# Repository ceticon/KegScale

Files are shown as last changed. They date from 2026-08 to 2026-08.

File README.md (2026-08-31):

# 🍺 KegScale

**KegScale** är en Raspberry Pi-baserad våg för att mäta hur mycket öl som finns kvar i ett Corneliusfat.

Systemet använder fyra lastceller tillsammans med en HX711 och en Raspberry Pi 5. Vikten läses kontinuerligt och presenteras i ett webbaserat gränssnitt byggt med Flask.

KegScale har två webbsidor:

- **KegScale Main** – ren visningssida för vikt, mängd öl och fyllnadsgrad.
- **KegScale Setup** – används för inställningar och hantering av vågen.

På så sätt kan huvudsidan visas för andra utan risk att någon av misstag ändrar inställningar eller nollställer vågen.

---

## 🖥️ KegScale Main

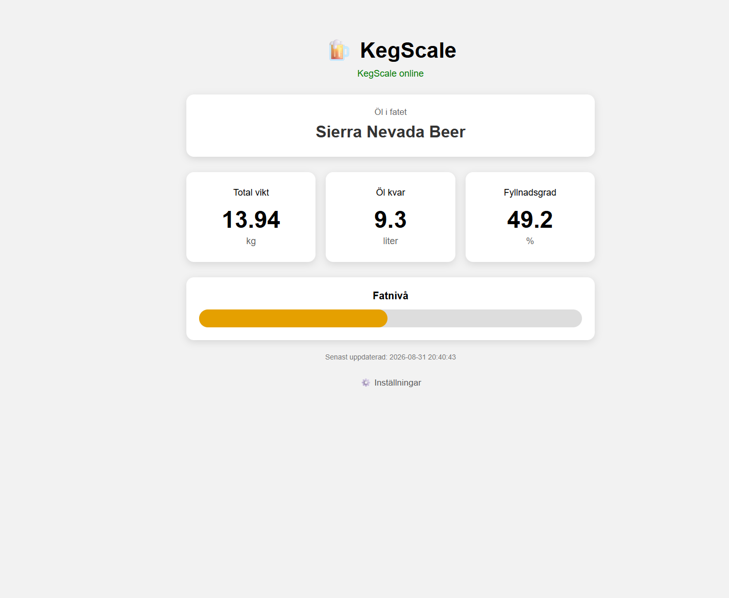
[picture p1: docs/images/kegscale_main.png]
KegScale Main


Huvudsidan finns på:

```text
http://<raspberry-pi-ip>:5000/
```

Den visar:

- Ölets namn
- Total vikt
- Mängd öl kvar i liter
- Fyllnadsgrad i procent
- Grafisk nivåindikator
- Online/offline-status
- Tidpunkt för senaste mätningen

Huvudsidan är avsedd som en **ren informationssida** och innehåller inga funktioner som ändrar KegScale.

Längst ner finns en diskret länk till inställningssidan.

---

## ⚙️ KegScale Setup

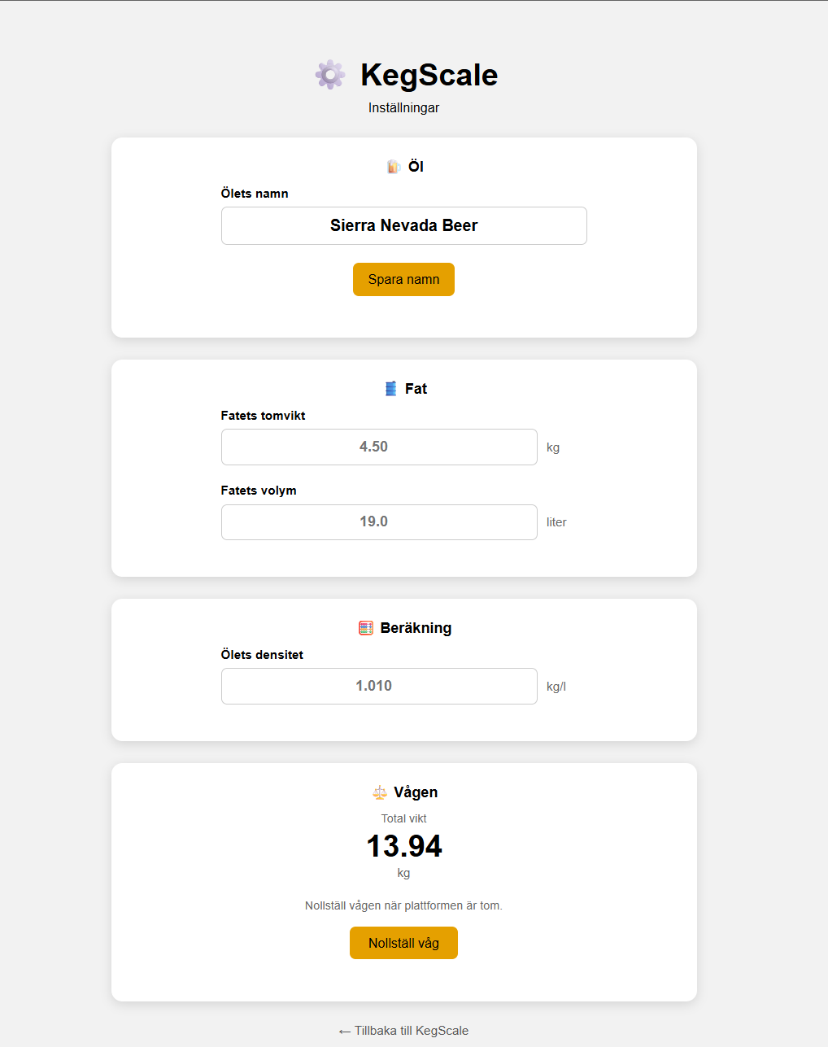
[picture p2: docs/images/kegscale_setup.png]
KegScale Setup


Inställningssidan finns på:

```text
http://<raspberry-pi-ip>:5000/setup
```

Setup-sidan används för konfiguration och handhavande.

Den innehåller:

- Ölets namn
- Fatets tomvikt
- Fatets volym
- Ölets densitet
- Aktuell total vikt
- Nollställning av vågen

Den aktuella vikten visas direkt på setup-sidan för att göra tareringen tydligare.

> **Observera:** Ölnamn och nollställning av vågen är implementerade.  
> Fatets tomvikt, volym och ölets densitet visas på Setup-sidan men ska kopplas till konfigurationen i ett kommande steg.

---

## 🔧 Hardware

KegScale använder:

- Raspberry Pi 5
- HX711 load cell amplifier
- 4 × 50 kg lastceller
- Kopplingskort för lastcellerna
- 19 liters Corneliusfat

Fyra 50 kg lastceller ger en nominell total kapacitet på cirka **200 kg**.

### HX711

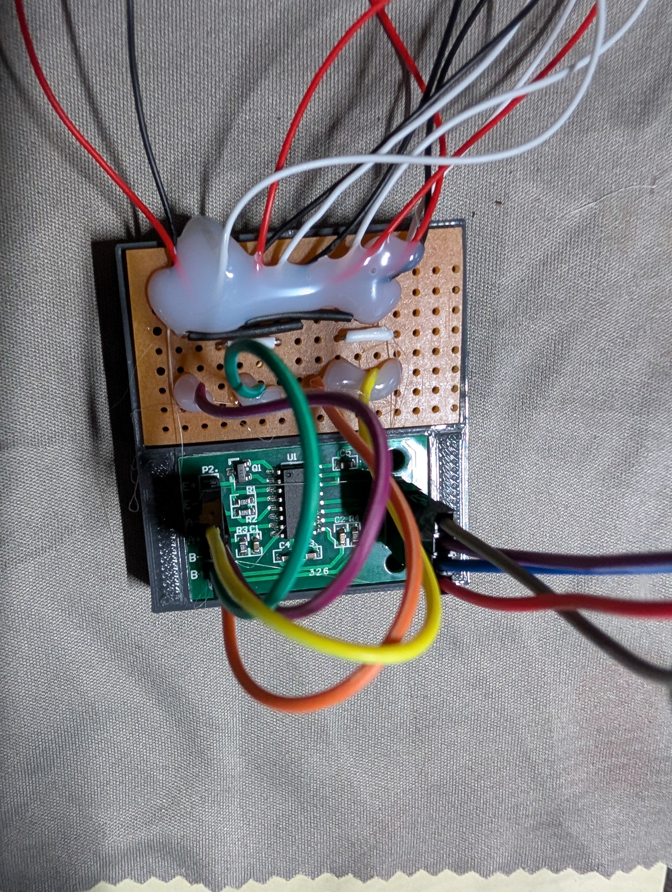
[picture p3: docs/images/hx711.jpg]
HX711


HX711 förstärker den mycket svaga signalen från lastcellerna och omvandlar den till ett digitalt 24-bitars mätvärde som Raspberry Pi kan läsa.

### Anslutning till Raspberry Pi

| HX711 | Raspberry Pi |
|---|---|
| DT / DATA | GPIO 6 |
| SCK / CLOCK | GPIO 5 |
| GND | GND |
| VCC | Matning |

Programmet använder BCM-numrering:

```python
DATA_PIN = 6
CLOCK_PIN = 5
```

---

## 🔌 Kopplingsschema

Fritzing-projekt och kopplingsschema finns i:

```text
hardware/
├── KegScale_bb.pdf
└── KegScale.fzz
```

`KegScale.fzz` kan öppnas och redigeras i Fritzing.

`KegScale_bb.pdf` innehåller kopplingsschemat i PDF-format.

---

## ⚖️ Så fungerar KegScale

Kommunikationen mellan hårdvara och webbgränssnitt ser ut så här:

```text
4 × Load cells
       │
       ▼
     HX711
       │
       ▼
Raspberry Pi GPIO
       │
       ▼
  kegscale.py
       │
       ▼
 kegscale.json
       │
       ▼
     Flask
       │
       ▼
   JavaScript
       │
       ▼
  Web browser
```

`kegscale.py` är den enda processen som kommunicerar direkt med GPIO och HX711.

Flask behöver därför inte komma åt GPIO utan läser den information som `kegscale.py` skriver till JSON.

Det gör att vågfunktionen och webbservern hålls separerade.

---

## 📏 Mätning och filtrering

För varje viktmätning:

1. 30 mätvärden läses från HX711.
2. Mätvärdena sorteras.
3. De 5 lägsta värdena tas bort.
4. De 5 högsta värdena tas bort.
5. Medelvärdet av resterande 20 mätningar beräknas.

Detta ger en stabilare vikt och minskar påverkan från enstaka störningar.

Små variationer runt noll filtreras också bort:

```python
if abs(vikt_gram) < 5:
    vikt_gram = 0.0
```

---

## 🎯 Kalibrering

Nuvarande kalibreringsfaktor:

```python
KALIBRERINGS_FAKTOR = 21.04
```

Vågen har kalibrerats med en känd vikt på cirka **3910 gram**.

Eftersom belastning gör HX711-råvärdet mer negativt beräknas vikten med:

```python
vikt_gram = -differens / KALIBRERINGS_FAKTOR
```

En separat fil finns för felsökning och kalibrering:

```text
debug_vikt.py
```

---

## 🍺 Konfiguration

Grundinställningarna finns i:

```text
config.json
```

Exempel:

```json
{
    "beer_name": "Munich Helles",
    "keg_tare_kg": 4.5,
    "keg_capacity_l": 19.0,
    "beer_density_kg_per_l": 1.01
}
```

### `beer_name`

Namnet på ölet som finns i fatet.

Ölnamnet kan ändras från **KegScale Setup** och visas sedan på **KegScale Main**.

### `keg_tare_kg`

Vikten på det tomma fatet.

Den verkliga tomvikten bör mätas för det Corneliusfat som används.

### `keg_capacity_l`

Fatets nominella volym i liter.

### `beer_density_kg_per_l`

Ölets ungefärliga densitet i kg/liter.

---

## 🧮 Beräkning av mängden öl

Först beräknas ölets vikt:

```text
Ölets vikt = Total vikt - Fatets tomvikt
```

Därefter beräknas volymen:

```text
Liter öl = Ölets vikt / Ölets densitet
```

Fyllnadsgraden beräknas med:

```text
Fyllnadsgrad = Liter öl / Fatets kapacitet × 100
```

Resultatet begränsas till:

```text
0 – 100 %
```

---

## 📄 Statusdata

`kegscale.py` skriver kontinuerligt aktuell information till:

```text
kegscale.json
```

Exempel:

```json
{
    "beer_name": "Munich Helles",
    "weight_g": 13945.1,
    "weight_kg": 13.945,
    "beer_weight_kg": 9.445,
    "beer_liters": 9.35,
    "fill_percent": 49.2,
    "keg_tare_kg": 4.5,
    "keg_capacity_l": 19.0,
    "beer_density_kg_per_l": 1.01,
    "timestamp": "2026-08-31 19:30:00"
}
```

`kegscale.json` är en runtime-fil och behöver normalt inte versionshanteras i Git.

---

## 🔄 Nollställning från Setup

Vågen kan nollställas från **KegScale Setup**.

Webbläsaren skickar:

```text
POST /api/tare
```

Flask skriver kommandot till:

```text
control.json
```

Exempel:

```json
{
    "tare": true
}
```

`kegscale.py` upptäcker kommandot, utför tareringen och återställer därefter kommandot.

```text
KegScale Setup
      │
      ▼
 POST /api/tare
      │
      ▼
    Flask
      │
      ▼
 control.json
      │
      ▼
 kegscale.py
      │
      ▼
    HX711
```

Flask kommunicerar alltså aldrig direkt med GPIO.

---

## ✏️ Ändra ölnamn

Ölnamnet ändras från **KegScale Setup**.

Flask använder:

```text
GET  /api/beer-name
POST /api/beer-name
```

När exempelvis:

```text
Munich Helles
```

ändras till:

```text
Czech Pilsner
```

sparas det nya namnet i `config.json`.

`kegscale.py` läser konfigurationen och det nya namnet visas därefter på KegScale Main.

---

## 📁 Projektstruktur

```text
KegScale/
├── .gitignore
├── config.json
├── debug_vikt.py
├── docs/
│   └── images/
│       ├── hx711.jpg
│       ├── kegscale_main.png
│       └── kegscale_setup.png
├── hardware/
│   ├── KegScale_bb.pdf
│   └── KegScale.fzz
├── kegscale.py
├── README.md
├── requirements.txt
├── test_vikt_pi5.py
└── web/
    ├── app.py
    ├── static/
    │   ├── script.js
    │   └── style.css
    └── templates/
        ├── index.html
        └── setup.html
```

Runtime-filerna:

```text
kegscale.json
control.json
```

exkluderas från Git via `.gitignore`.

---

## 🐍 Python environment

Skapa en virtuell Python-miljö:

```bash
python3 -m venv myenv
```

Aktivera den:

```bash
source myenv/bin/activate
```

Installera beroenden:

```bash
pip install -r requirements.txt
```

---

## 🚀 Starta KegScale

KegScale består av två separata processer:

1. Vågen
2. Flask-webbservern

### Terminal 1 – KegScale

```bash
cd ~/Projects/KegScale
source myenv/bin/activate
python kegscale.py
```

### Terminal 2 – Flask

```bash
cd ~/Projects/KegScale
source myenv/bin/activate
cd web
python app.py
```

Flask-servern körs på:

```text
0.0.0.0:5000
```

### KegScale Main

```text
http://<raspberry-pi-ip>:5000/
```

### KegScale Setup

```text
http://<raspberry-pi-ip>:5000/setup
```

---

## 🌐 API

### Läs vågdata

```text
GET /api/weight
```

Returnerar bland annat:

- Ölnamn
- Total vikt
- Mängd öl
- Fyllnadsgrad
- Tidstämpel
- Online/offline-status

### Nollställ vågen

```text
POST /api/tare
```

### Läs ölnamn

```text
GET /api/beer-name
```

### Ändra ölnamn

```text
POST /api/beer-name
```

Exempel:

```json
{
    "beer_name": "Munich Helles"
}
```

---

## ✅ Current features

- [x] Raspberry Pi 5
- [x] HX711 communication
- [x] 4 × 50 kg load cells
- [x] Digital filtering
- [x] Scale calibration
- [x] Weight in grams and kilograms
- [x] Beer volume calculation
- [x] Keg fill percentage
- [x] JSON status
- [x] Flask web interface
- [x] Automatic web updates
- [x] Online/offline detection
- [x] Graphical keg level
- [x] Separate Main and Setup pages
- [x] Read-only Main page
- [x] Editable beer name from Setup
- [x] Web-based scale tare
- [x] Live total weight on Setup page
- [x] Hardware documentation
- [x] Fritzing project and PDF wiring diagram

---

## 🔮 Planned features

- [ ] Save keg tare weight from Setup
- [ ] Use current scale weight as keg tare weight
- [ ] Save keg capacity from Setup
- [ ] Save beer density from Setup
- [ ] Support different keg sizes
- [ ] Save scale offset between restarts
- [ ] Automatic startup with systemd
- [ ] Historical consumption data
- [ ] Multiple keg support

---

## 📌 Status

KegScale är nu ett fungerande Raspberry Pi-baserat mätsystem med separat vågprocess och Flask-webbserver.

Vågen är kalibrerad och testad. **KegScale Main** visar aktuell vikt, mängden öl och fatets fyllnadsgrad, medan **KegScale Setup** används för inställningar och tarering.

Nästa utvecklingssteg är att göra fatets tomvikt, volym och ölets densitet fullt redigerbara från Setup-sidan.

🍺 **Current keg: Munich Helles**

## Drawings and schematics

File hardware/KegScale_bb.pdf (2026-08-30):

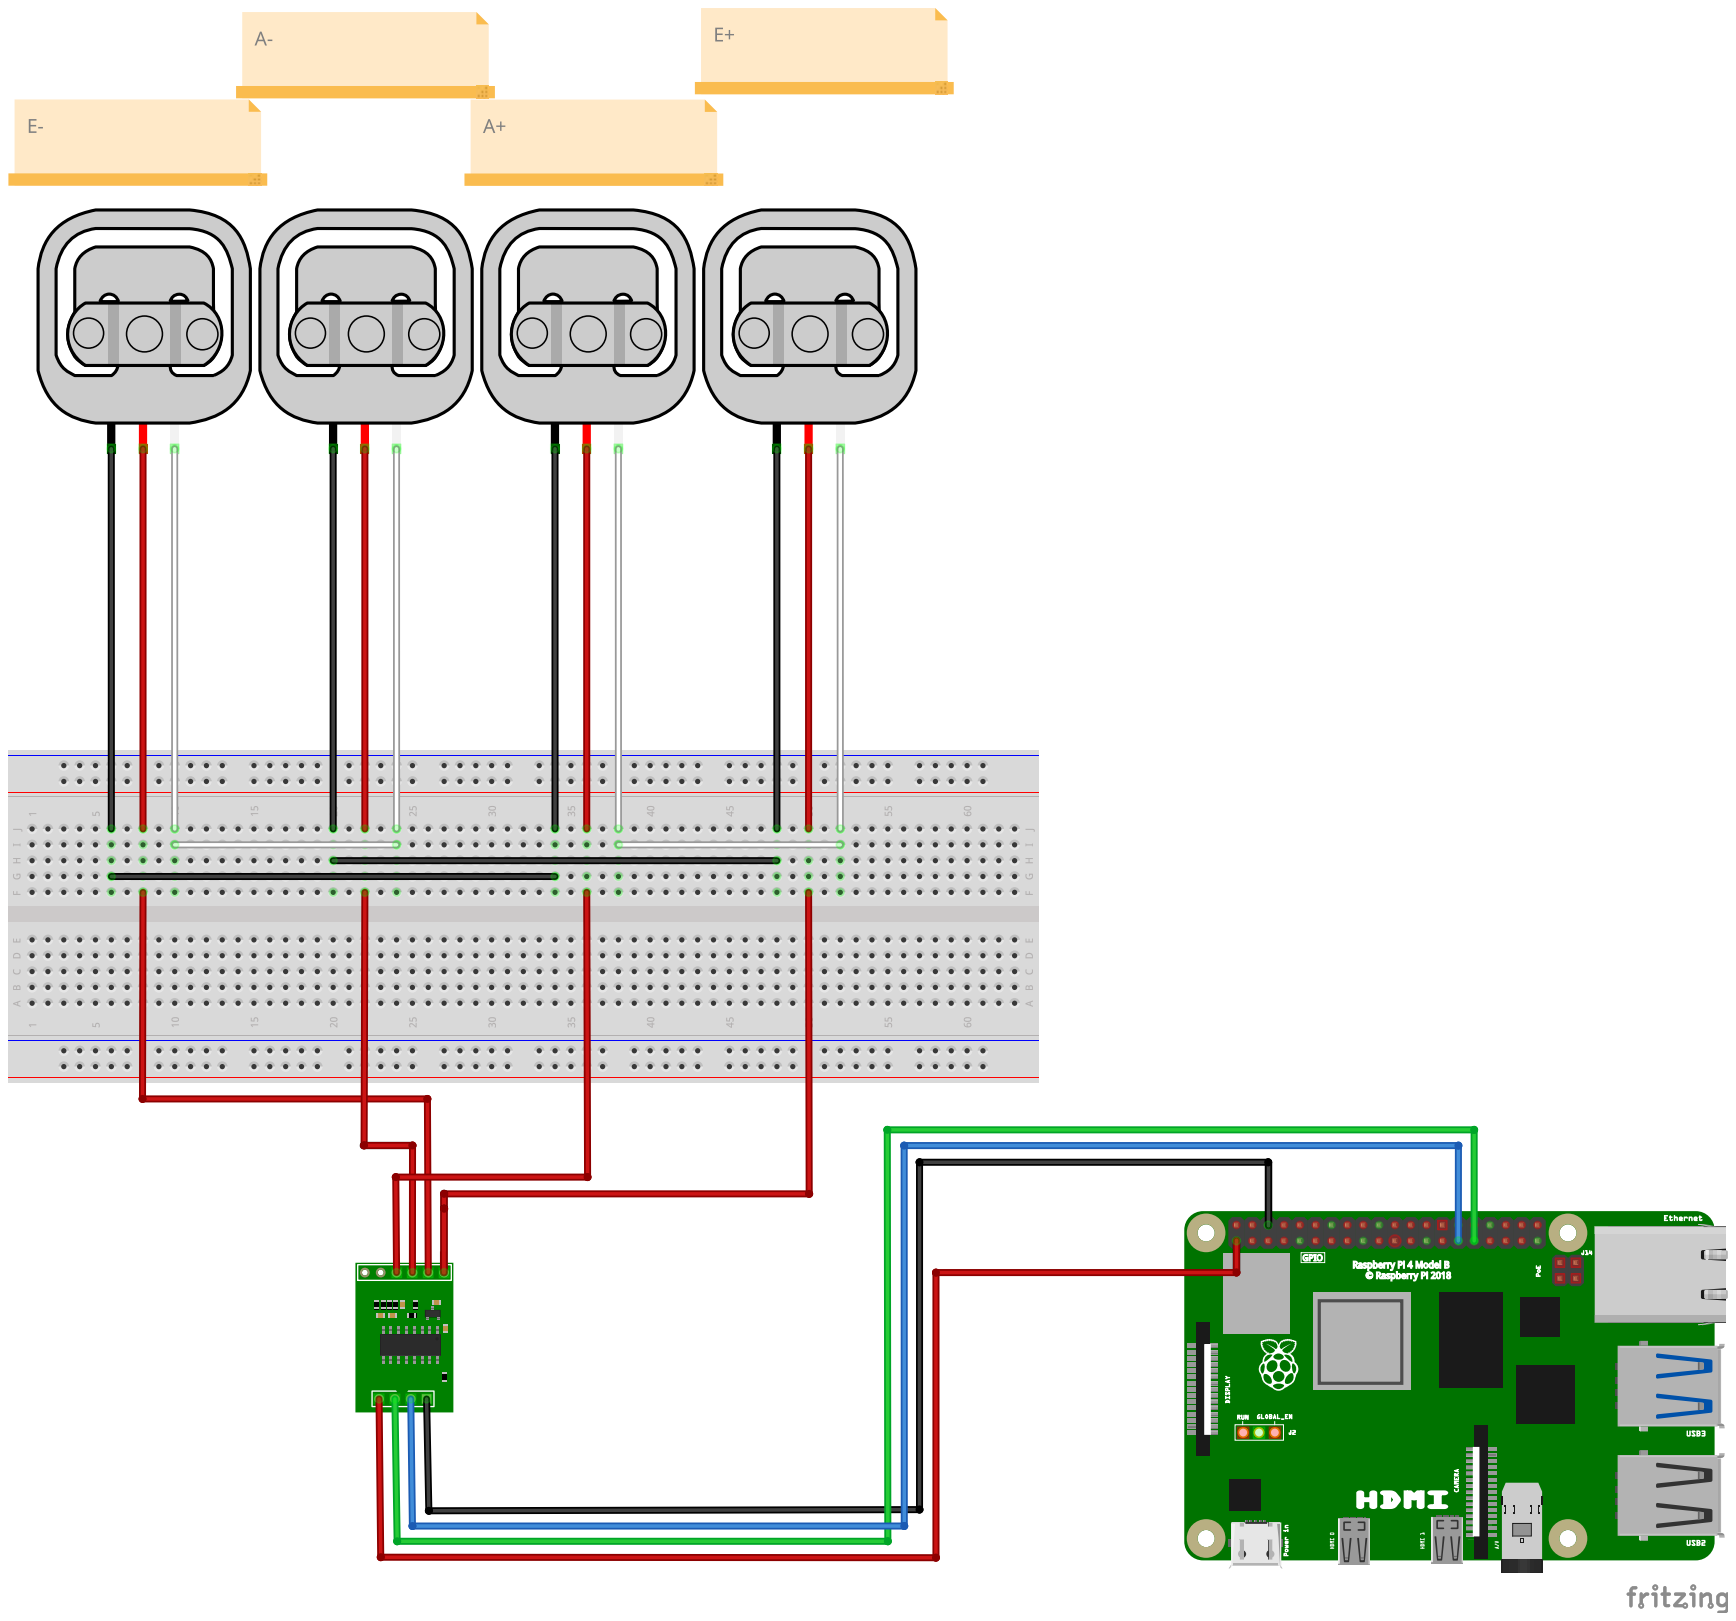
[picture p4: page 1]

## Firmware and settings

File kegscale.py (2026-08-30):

import time
import json
from datetime import datetime
import RPi.GPIO as GPIO

DATA_PIN = 6
CLOCK_PIN = 5

KALIBRERINGS_FAKTOR = 21.04

ANTAL_MATNINGAR = 30
ANTAL_BORTTAGNA = 5

JSON_FIL = "kegscale.json"
CONFIG_FIL = "config.json"
CONTROL_FIL = "control.json"


GPIO.setmode(GPIO.BCM)
GPIO.setup(CLOCK_PIN, GPIO.OUT)
GPIO.setup(DATA_PIN, GPIO.IN)


# -------------------------------------------------
# ÅTERSTÄLL HX711
# -------------------------------------------------

def reset_hx711():
    print("Återställer HX711...")

    GPIO.output(CLOCK_PIN, GPIO.HIGH)
    time.sleep(0.005)

    GPIO.output(CLOCK_PIN, GPIO.LOW)
    time.sleep(0.2)


# -------------------------------------------------
# LÄS ETT RÅVÄRDE FRÅN HX711
# -------------------------------------------------

def las_hx711():
    for _ in range(1000):

        if GPIO.input(DATA_PIN) == 0:
            break

        time.sleep(0.001)

    else:
        return None


    data_bits = 0

    for _ in range(24):

        GPIO.output(CLOCK_PIN, GPIO.HIGH)

        data_bits = (
            (data_bits << 1)
            | GPIO.input(DATA_PIN)
        )

        GPIO.output(CLOCK_PIN, GPIO.LOW)


    # 25:e pulsen
    # Kanal A, Gain 128

    GPIO.output(CLOCK_PIN, GPIO.HIGH)
    GPIO.output(CLOCK_PIN, GPIO.LOW)


    # Konvertera signed 24-bit

    if data_bits & 0x800000:
        data_bits -= 0x1000000


    return data_bits


# -------------------------------------------------
# FILTRERAD AVLÄSNING
# -------------------------------------------------

def las_filtrerat_varde():

    matningar = []


    while len(matningar) < ANTAL_MATNINGAR:

        varde = las_hx711()

        if varde is not None:
            matningar.append(varde)

        time.sleep(0.02)


    matningar.sort()


    filtrerade = matningar[
        ANTAL_BORTTAGNA:
        -ANTAL_BORTTAGNA
    ]


    return (
        sum(filtrerade)
        / len(filtrerade)
    )


# -------------------------------------------------
# TARERING
# -------------------------------------------------

def tare():

    print()
    print("Nollställer vågen...")

    time.sleep(1)


    offset = las_filtrerat_varde()


    print(
        f"Ny offset: {offset:.0f}"
    )

    print()


    return offset


# -------------------------------------------------
# LÄS CONFIG
# -------------------------------------------------

def las_config():

    try:

        with open(CONFIG_FIL, "r") as fil:
            return json.load(fil)


    except Exception as e:

        print(
            f"Kunde inte läsa {CONFIG_FIL}: {e}"
        )


        return {

            "beer_name": "Okänd öl",

            "keg_tare_kg": 4.5,

            "keg_capacity_l": 19.0,

            "beer_density_kg_per_l": 1.01
        }


# -------------------------------------------------
# LÄS CONTROL
# -------------------------------------------------

def las_control():

    try:

        with open(CONTROL_FIL, "r") as fil:
            return json.load(fil)


    except Exception:

        return {
            "tare": False
        }


# -------------------------------------------------
# ÅTERSTÄLL CONTROL
# -------------------------------------------------

def aterstall_control():

    data = {
        "tare": False
    }


    with open(CONTROL_FIL, "w") as fil:

        json.dump(
            data,
            fil,
            indent=4
        )


# -------------------------------------------------
# SKRIV KEGSCALE.JSON
# -------------------------------------------------

def skriv_json(vikt_gram):

    config = las_config()


    beer_name = config.get(
        "beer_name",
        "Okänd öl"
    )


    total_vikt_kg = (
        vikt_gram
        / 1000.0
    )


    keg_tare_kg = config.get(
        "keg_tare_kg",
        4.5
    )


    keg_capacity_l = config.get(
        "keg_capacity_l",
        19.0
    )


    beer_density = config.get(
        "beer_density_kg_per_l",
        1.01
    )


    # ---------------------------------------------
    # ÖLETS VIKT
    # ---------------------------------------------

    beer_weight_kg = (
        total_vikt_kg
        - keg_tare_kg
    )


    if beer_weight_kg < 0:

        beer_weight_kg = 0.0


    # ---------------------------------------------
    # ÖLETS VOLYM
    # ---------------------------------------------

    beer_liters = (
        beer_weight_kg
        / beer_density
    )


    # ---------------------------------------------
    # FYLLNADSGRAD
    # ---------------------------------------------

    fill_percent = (
        beer_liters
        / keg_capacity_l
    ) * 100.0


    if fill_percent < 0:
        fill_percent = 0.0


    if fill_percent > 100:
        fill_percent = 100.0


    # ---------------------------------------------
    # JSON DATA
    # ---------------------------------------------

    data = {

        "beer_name": beer_name,

        "weight_g": round(
            vikt_gram,
            1
        ),

        "weight_kg": round(
            total_vikt_kg,
            3
        ),

        "beer_weight_kg": round(
            beer_weight_kg,
            3
        ),

        "beer_liters": round(
            beer_liters,
            2
        ),

        "fill_percent": round(
            fill_percent,
            1
        ),

        "keg_tare_kg": keg_tare_kg,

        "keg_capacity_l": keg_capacity_l,

        "beer_density_kg_per_l": beer_density,

        "timestamp":
            datetime.now().strftime(
                "%Y-%m-%d %H:%M:%S"
            )
    }


    with open(JSON_FIL, "w") as fil:

        json.dump(
            data,
            fil,
            indent=4,
            ensure_ascii=False
        )


# =================================================
# START
# =================================================

reset_hx711()

offset = tare()


print("--- KEG-SCALE STARTAD ---")
print("Tryck Ctrl+C för att avsluta.")
print()
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

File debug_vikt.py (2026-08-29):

import time
import RPi.GPIO as GPIO

DATA_PIN = 6
CLOCK_PIN = 5

KALIBRERINGS_FAKTOR = 20.19
ANTAL_MATNINGAR = 30

GPIO.setmode(GPIO.BCM)
GPIO.setup(CLOCK_PIN, GPIO.OUT)
GPIO.setup(DATA_PIN, GPIO.IN)

print("Gör en hård återställning av HX711...")

# Power-down / reset
GPIO.output(CLOCK_PIN, GPIO.HIGH)
time.sleep(0.005)

# Starta HX711 igen
GPIO.output(CLOCK_PIN, GPIO.LOW)
time.sleep(0.2)


def las_hx711_direkt():
    """Läser ett råvärde från HX711."""

    for _ in range(1000):
        if GPIO.input(DATA_PIN) == 0:
            break
        time.sleep(0.001)
    else:
        return None

    data_bits = 0

    for _ in range(24):
        GPIO.output(CLOCK_PIN, GPIO.HIGH)

        data_bits = (
            (data_bits << 1)
            | GPIO.input(DATA_PIN)
        )

        GPIO.output(CLOCK_PIN, GPIO.LOW)

    # 25:e klockpulsen:
    # Kanal A, Gain 128
    GPIO.output(CLOCK_PIN, GPIO.HIGH)
    GPIO.output(CLOCK_PIN, GPIO.LOW)

    # Konvertera 24-bit signed
    if data_bits & 0x800000:
        data_bits -= 0x1000000

    return data_bits


def las_filtrerat_varde():
    """
    Tar 10 mätningar.
    Tar bort högsta och lägsta.
    Returnerar medelvärdet av de återstående 8.
    """

    matningar = []

    while len(matningar) < ANTAL_MATNINGAR:

        varde = las_hx711_direkt()

        if varde is not None:
            matningar.append(varde)

        time.sleep(0.02)

    # Sortera från lägst till högst
    matningar.sort()

    # Ta bort de 5 lägsta och 5 högsta värdena
    filtrerade = matningar[5:-5]

    # Medelvärde av de 20 återstående
    medel = sum(filtrerade) / len(filtrerade)

    return medel


# -------------------------------------------------
# NOLLSTÄLLNING
# -------------------------------------------------

print()
print("Nollställer vågen...")
print("Vågen måste vara helt tom.")
print()

time.sleep(2)

offset = las_filtrerat_varde()

print(f"Nollställning klar.")
print(f"Offset: {offset:.0f}")
print(f"Kalibreringsfaktor: {KALIBRERINGS_FAKTOR}")
print()
print("--- STARTAR VIKTMÄTNING ---")
print("Tryck Ctrl+C för att avsluta.")
print()


try:

    while True:

        aktuellt_varde = las_filtrerat_varde()

        differens = aktuellt_varde - offset

        vikt_gram = differens / KALIBRERINGS_FAKTOR

        # Små variationer runt noll visas som 0
        if abs(vikt_gram) < 5:
            vikt_gram = 0.0

        print(
            f"Rå: {aktuellt_varde:10.0f} | "
            f"Skillnad: {differens:8.0f} | "
            f"Vikt: {vikt_gram:8.1f} g",
            end="\r"
        )

        time.sleep(0.1)


except KeyboardInterrupt:

    print()
    print()
    print("Programmet avslutat.")


finally:

    GPIO.cleanup()
